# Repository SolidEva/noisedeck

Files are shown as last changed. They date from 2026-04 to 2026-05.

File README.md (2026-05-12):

# noisedeck

a cyberdeck for dealing in noise
runs [prawnix](http://github.com/SolidEva/prawnix)

## v2

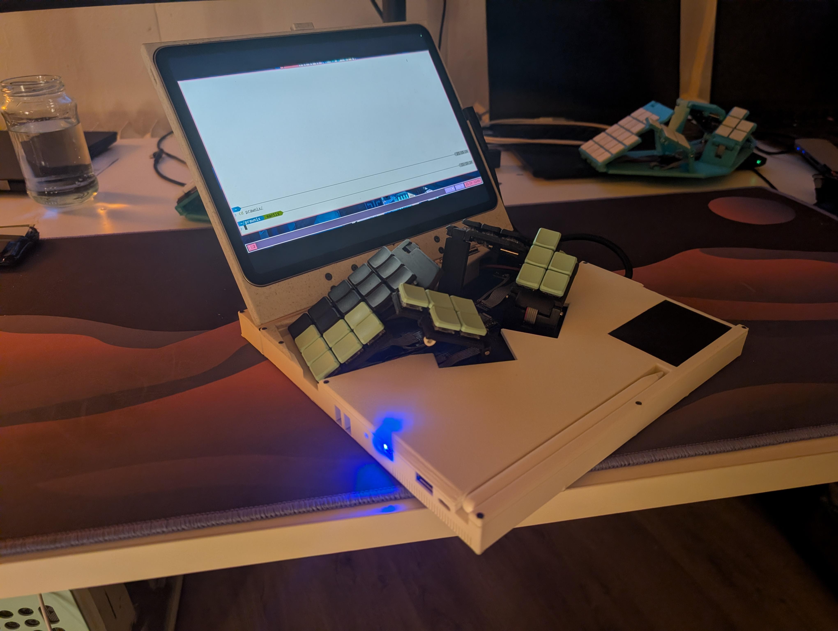
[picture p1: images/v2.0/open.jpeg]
front_open


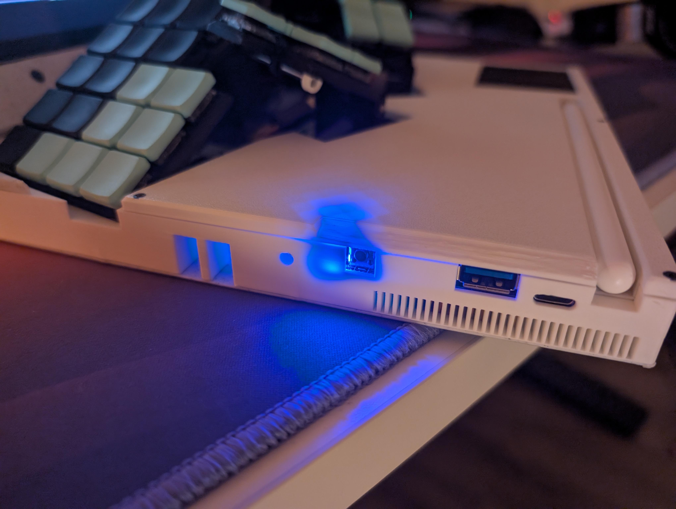
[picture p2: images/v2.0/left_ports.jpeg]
ports_left


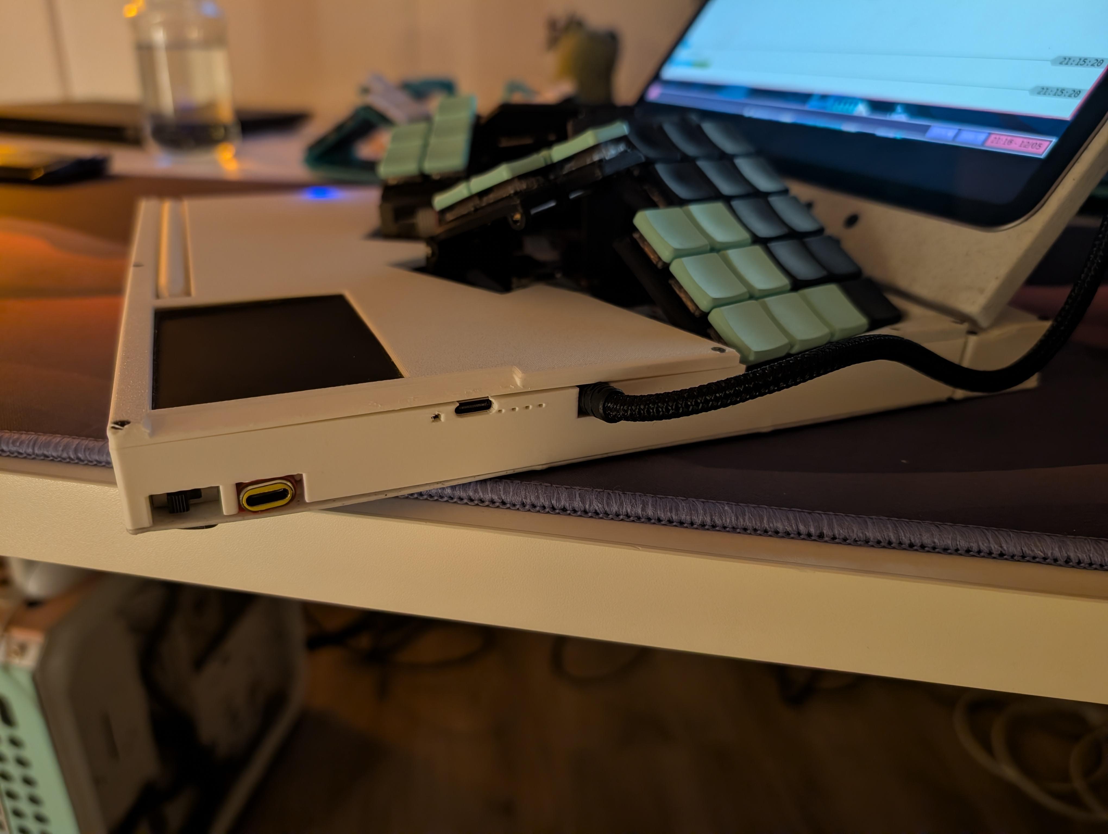
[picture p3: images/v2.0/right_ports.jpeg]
ports_right


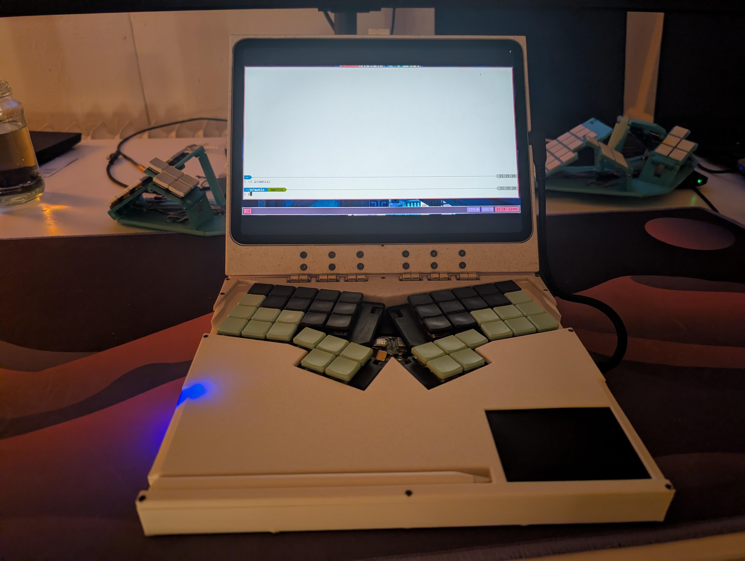
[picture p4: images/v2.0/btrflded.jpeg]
btrfld_folded


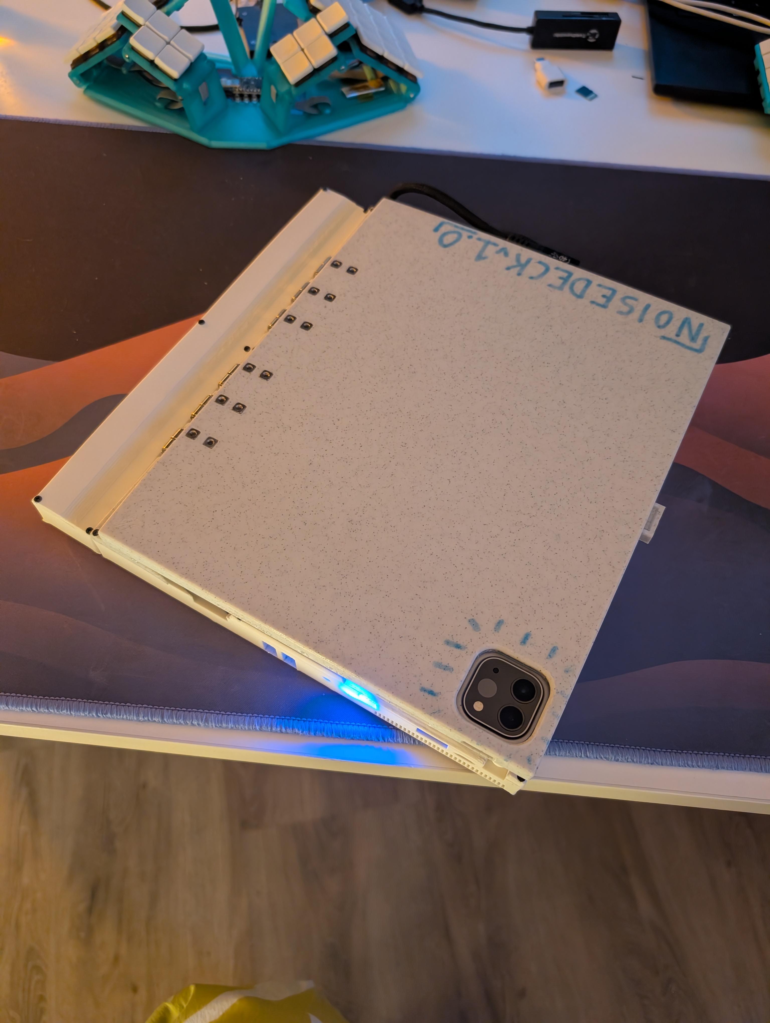
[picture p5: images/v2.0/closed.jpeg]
closed


### features
- rk3588s SBC (firefly roc-rk3588s-pc)
- btrfld keyboard
- trackpad
- ipad: magnetically mounted acting as screen via usbc hdmi capture card
- 1x usb c data port
- 2x usb c charge port (one for ipad, other for main battery, supports usbc power delivery!)
- 1x usb a 3.0 port
- ipad pencil and charging cradle

### parts
ipad :p

btrfld keyboard: https://github.com/SolidHal/btrfld

rk3588s SBC: https://en.t-firefly.com/product/industry/rocrk3588spc#spec

hinges:
https://www.amazon.com/gp/product/B0BFWNJMCY/

hinge fasteners:
M3x16
M3 threaded, DIN 562 flat square nuts: https://www.amazon.com/M3nS-Printers-Stainless-Conform-Quantity/dp/B0BD2N9KTV

power switches:
https://www.amazon.com/dp/B075RC6TFB

apple pencil charging cradle:
https://www.amazon.com/Paiholy-Compatible-Generation-Lightweight-Convenient/dp/B0BMB7362T

midcase fasteners (plastic to plastic):
m2x5 and m2x6 tapered flat head self taping screws

cheap ipad magnetic folio case, torn apart to make the ipad mount

usbc right angle extension: https://www.amazon.com/dp/B0B71BZ4YF

battery & charging:
- 3x 18650s
- 3s BMS: https://de.aliexpress.com/item/1005006064385669.html
- usbc PD IP2369 based  battery charger board: https://de.aliexpress.com/item/1005008766304319.html
- XT30 plugs

cooling:
- fan: https://www.digikey.de/en/products/detail/wakefield-thermal-solutions/DB0620505H1A-BT0/12610355
- heatsink: https://www.digikey.de/en/products/detail/advanced-thermal-solutions-inc/ATS-1108-C1-R0/4146489
- screws, m3x5mm for heatsink, m2 for fan

video:
- a flat HDMI cable like: https://www.amazon.de/dp/B01787KZVG
- usbc 1080p hdmi capture card with usbc power delivery (lets us charge the ipad while in use): https://www.amazon.de/dp/B0DQDC3H46
- 4in usbc extension, for ipad power delivery, like https://www.amazon.com/dp/B0CSJMCCXW

- 4 port usb hub pcb: https://www.adafruit.com/product/5997

- mnt reform trackpad: https://shop.mntre.com/products/mnt-reform-capacitive-trackpad-module

### Assembly Notes

- glue eyeglass nosepads to bottomcase for feet
- hinges need to be filed/ground shorter on the side that would otherwise stick out through the bottom case
- cleaning out the hinge holes in the ipad enclosure is annoying. Recommend using a 46 gauge drill bit
- tear down the ipad folio case to just the parts required to hold the magnets in place. lets call this the "case core"
  - attach a thin film to the side of the case core that magnetizes to the ipad
  - superglue the case core into the ipad enclosure so that the ipad is held into the ipad enclosure magnetically

- battery wiring
    - so the schematic is cells --> BMS <----> ip2368
                                       |
                                    controller

more notes in build_notes.md

# V1

a cyberdeck for dealing in noise, v1

front_open

back_art

ports

btrfld_folded

closed

## features
- btrfld keyboard
- trackpad
- headphone jack
- mic jack
- 1x usb c data port
- 1x usb c charge port
- 1x usb a port
- ipad: magnetically mounted
- ipad pencil and charging cradle
- rpi zero 2 w + 5000mah battery

future:
- extra keys in topcase for common hotkeys(?)
- choc key one octave keyboard in topcase(?)
- pitch joystick/wheel that snaps back to the center

the rpi zero 2 w is ran so its usb is in gadget mode, so it tells the ipad it is an ethernet device.
with this you can setup a local network and ssh directly from the ipad to the rpi without using wifi
this leaves the wifi chipset useful for other things

## parts
hinges:
https://www.amazon.com/gp/product/B0BFWNJMCY/

hinge fasteners:
M3x8 countersunk fasteners: https://www.amazon.com/HanTof-Countersunk-Machine-Wrenches-Threaded/dp/B0B9HWVV61
M3x10 countersunk fasteners
M3 threaded, DIN 562 flat square nuts: https://www.amazon.com/M3nS-Printers-Stainless-Conform-Quantity/dp/B0BD2N9KTV

power switches:
https://www.amazon.com/dp/B075RC6TFB

apple pencil charging cradle:
https://www.amazon.com/Paiholy-Compatible-Generation-Lightweight-Convenient/dp/B0BMB7362T

midcase fasteners (plastic to plastic):
m2x5 and m2x6 tapered flat head self taping screws

cheap ipad magnetic folio case

btrfld keyboard: https://github.com/SolidHal/btrfld

usbc to 3x usbc (2 data, one power): https://www.amazon.com/gp/product/B09PFR2J82

usbc to 4x usbA : https://www.amazon.com/dp/B09N36LZSQ

usbA dac: https://www.amazon.com/dp/B01DLY3IW8

usbc right angle extension: https://www.amazon.com/dp/B0B71BZ4YF

rpi zero 2 w

5000mah battery

pcb usb hub https://www.amazon.com/dp/B09FX4QN4J

used to get a power only usbc port for charging the rpi battery: https://www.amazon.com/dp/B07VBV1PY5

## Assembly notes

case:
- use 52 gauge drill bit to clean out midcase holes for the m2 screws
- use 46 gauge drill bit to clean out topcase holes for the m2 screws
- use chamfer bit on bottomcase holes screws sit flush
- glue eyeglass nosepads to bottomcase for feet
- hinges need to be filed/ground shorter on the side that would otherwise stick out through the bottom case
- cleaning out the hinge holes in the ipad enclosure is annoying. Recommend using a 46 gauge drill bit
- tear down the ipad folio case to just the parts required to hold the magnets in place. lets call this the "case core"
  - attach a thin film to the side of the case core that magnetizes to the ipad
  - superglue the case core into the ipad enclosure so that the ipad is held into the ipad enclosure magnetically

- the 5000mah battery pack fits nicely under the dac.

dac must have a power switch, otherwise the ipad will always use it by default and never allow usage of the speakers

wiring:

The wiring is a bit messy, but it works and all fits with plenty of space:

wiring

ipad -> extension -> usbc/usbc 3 way splitter -> one usbc charging port, one usbc data port, and the usbc to usbA splitter

usbA splitter:
- port 1:
  - data and ground to headphone port dac
  - power to two switches on the left side of the noisedeck. One switch to the dac, other to pencil charger. Only use one of these at a time.
- port 2:
  - data only to rpi zero 2w data port. Power to nowhere
- port 3:
  - to pcb usb hub:
    - port 3a:
      - to btrfld
    - port 3b:
      - to trackpad
- port 4:
  - glued into the left side of the noisedeck, externally accessible usbA port

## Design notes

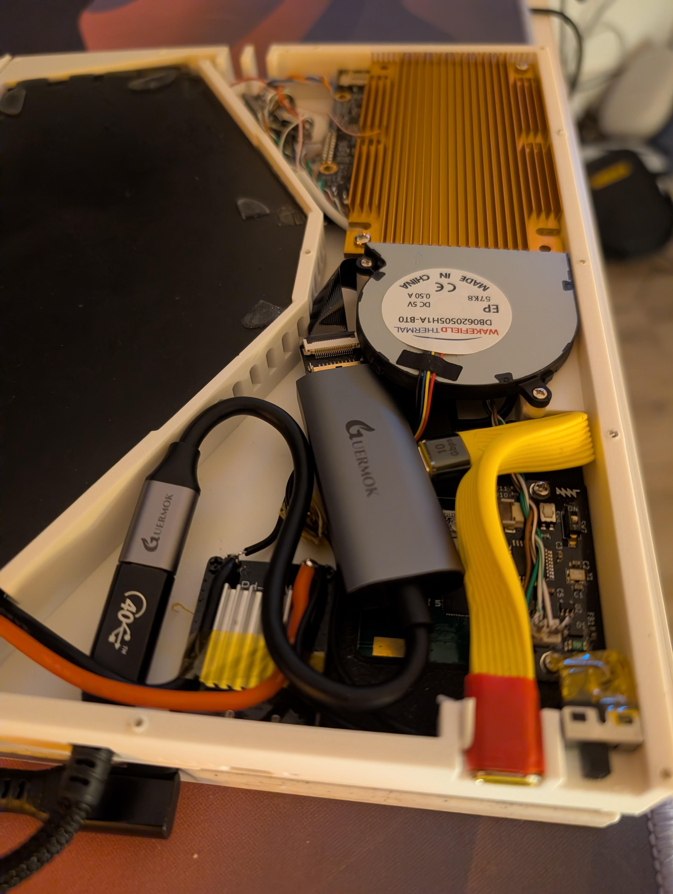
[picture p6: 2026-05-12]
images/v2.0/guts_closeup.jpeg

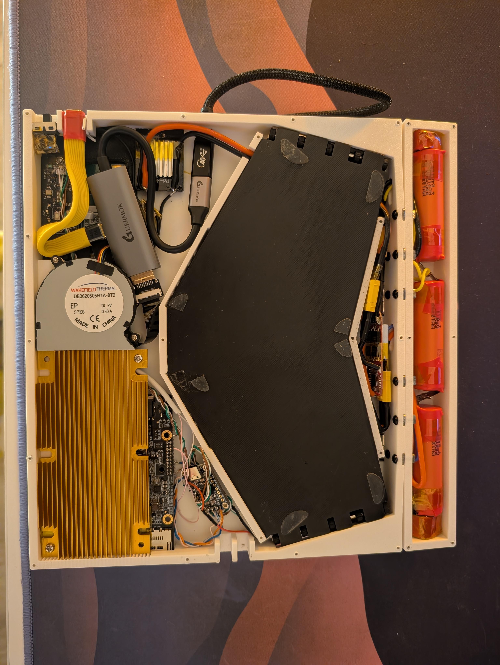
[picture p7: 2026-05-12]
images/v2.0/guts.jpeg

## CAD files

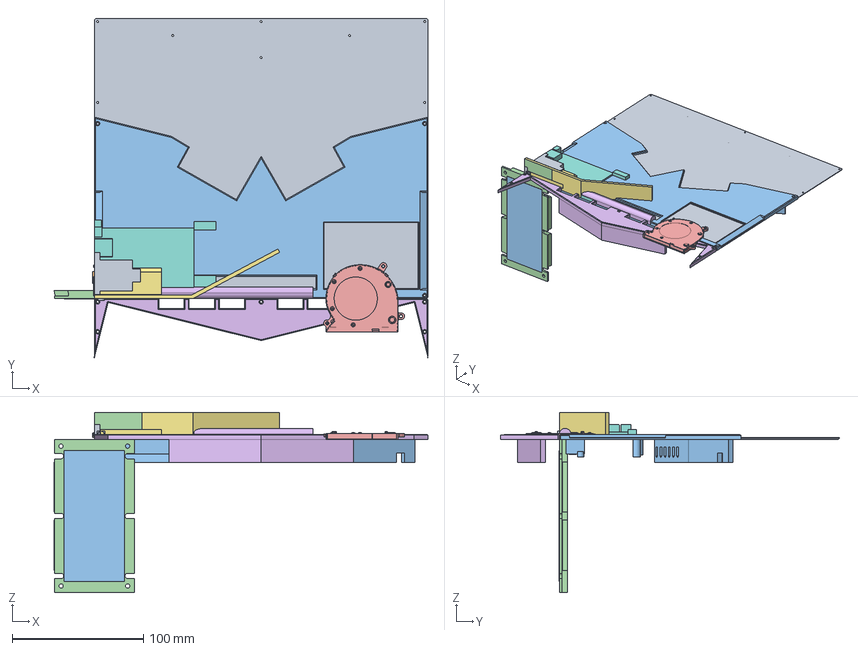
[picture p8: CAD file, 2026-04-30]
cad/case_assembly.FCStd
285.4 x 258.9 x 137.5 mm
bottomcase
usbc Charging port
ATS117061006-1108-C1-R0_FUSED
ATS117061006-1108-C1-R0_FUSED001
Dg12C04352tvdg
apple_pencil
audio_port_dac
controller
headphone_mic_jack
hinge_half
topcase_lower
topcase_lower_btrfld_support_center
topcase_lower_btrfld_support_outer
topcase_upper
topcase_upper_btrfld_support
trackpad_placeholder
usba_port
usba_port_smaller
usbc_cable_head
usbc_port
usbc_port_smaller

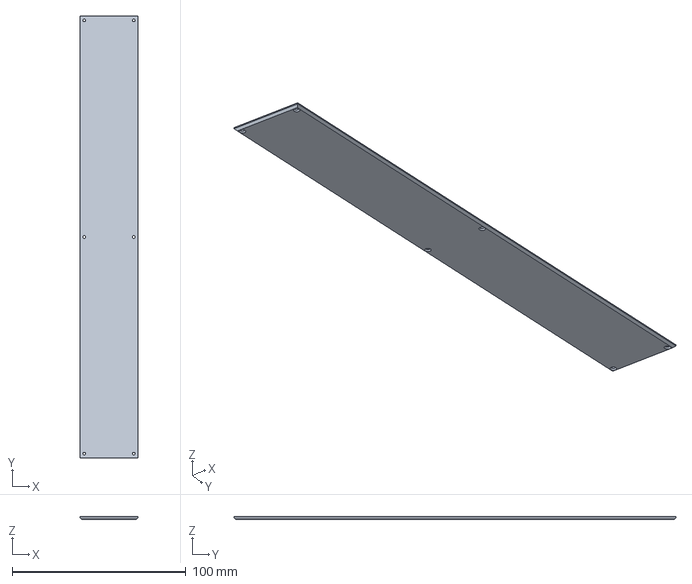
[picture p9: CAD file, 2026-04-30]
cad/stls/case_assembly-battery_bottomcase.3mf
33.5 x 254.6 x 1.50 mm

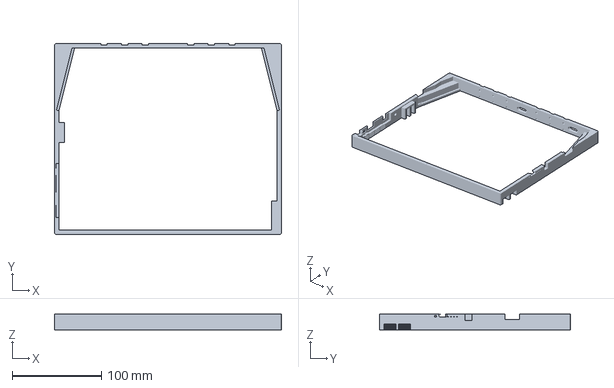
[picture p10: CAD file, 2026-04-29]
cad/stls/case_assembly-midcase.3mf
254.6 x 213.9 x 17.7 mm

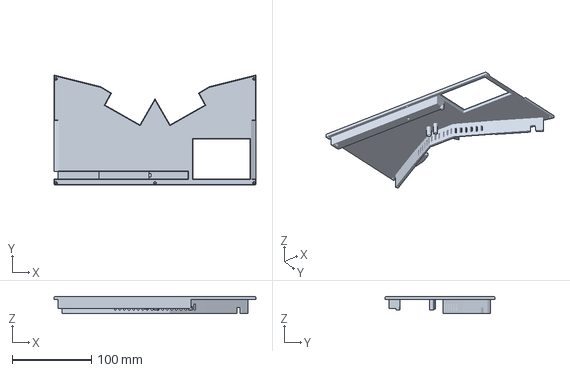
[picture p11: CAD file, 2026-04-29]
cad/stls/case_assembly-topcase_lower.3mf
254.6 x 138.6 x 21.7 mm

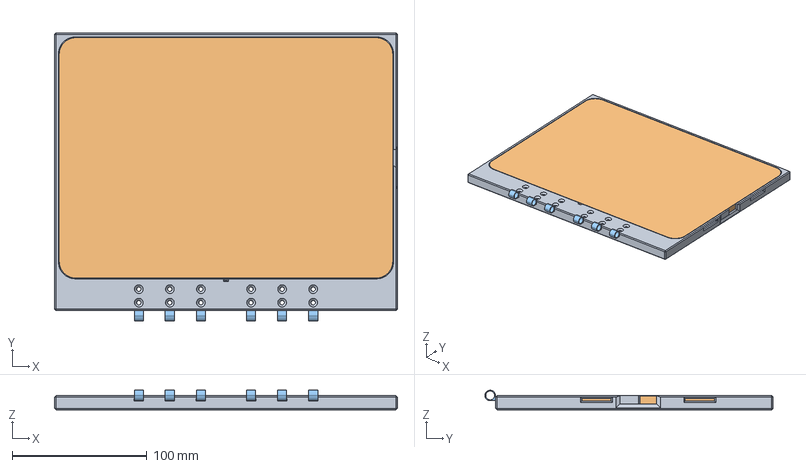
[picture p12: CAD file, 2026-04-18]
cad/lcd_assembly.FCStd
254.6 x 213.9 x 14.6 mm
ipad_enclosure
ipad11in4thgen
hinge_half x 6

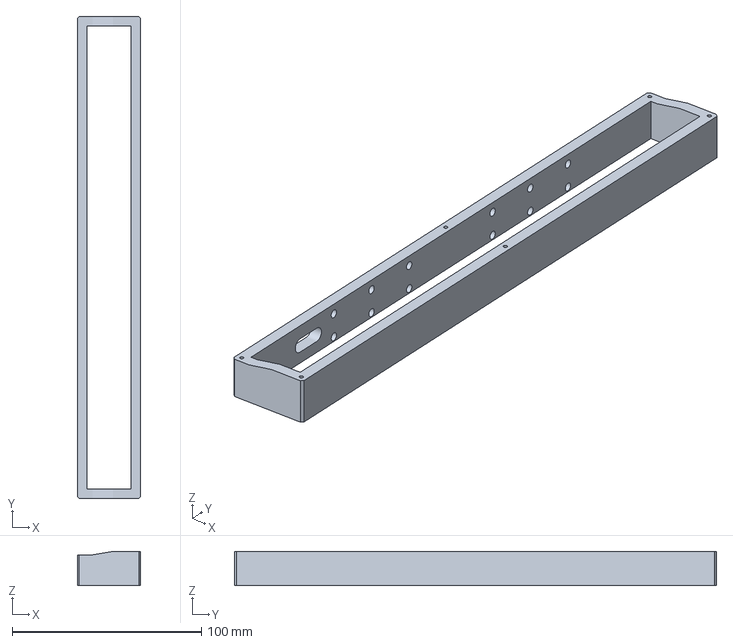
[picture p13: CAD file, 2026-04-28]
cad/stls/case_assembly-battery_midcase.3mf
33.5 x 254.6 x 18.0 mm

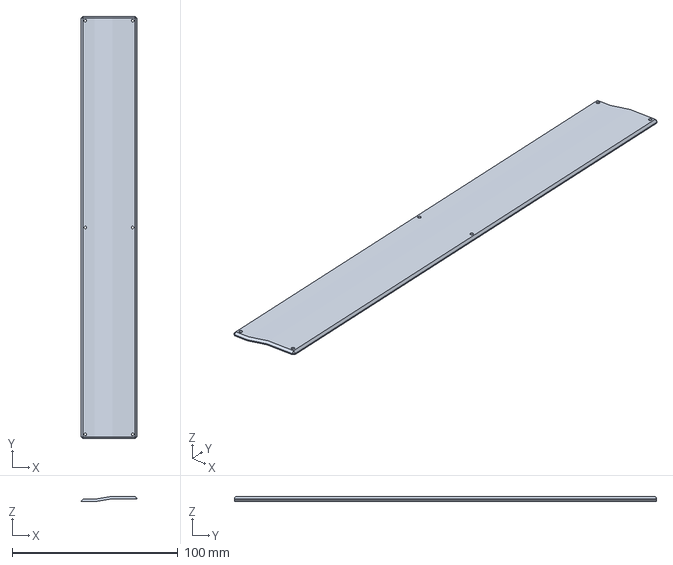
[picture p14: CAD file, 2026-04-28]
cad/stls/case_assembly-battery_topcase.3mf
33.5 x 254.6 x 3.30 mm

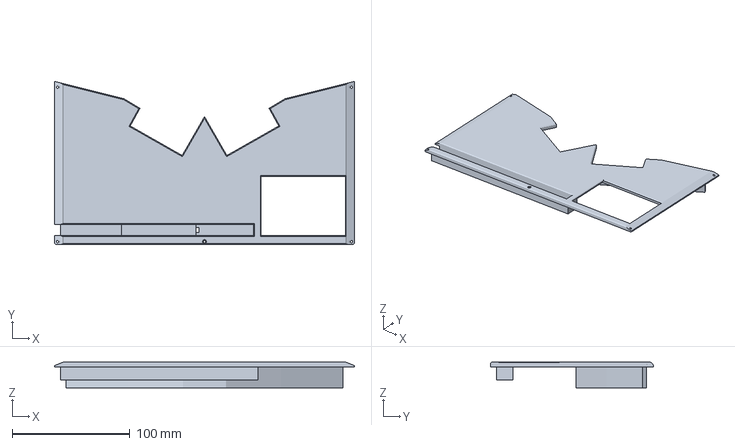
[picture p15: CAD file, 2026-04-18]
cad/stls/case_assembly-FullAssemblytopcase_lower001.3mf
254.6 x 138.6 x 21.7 mm

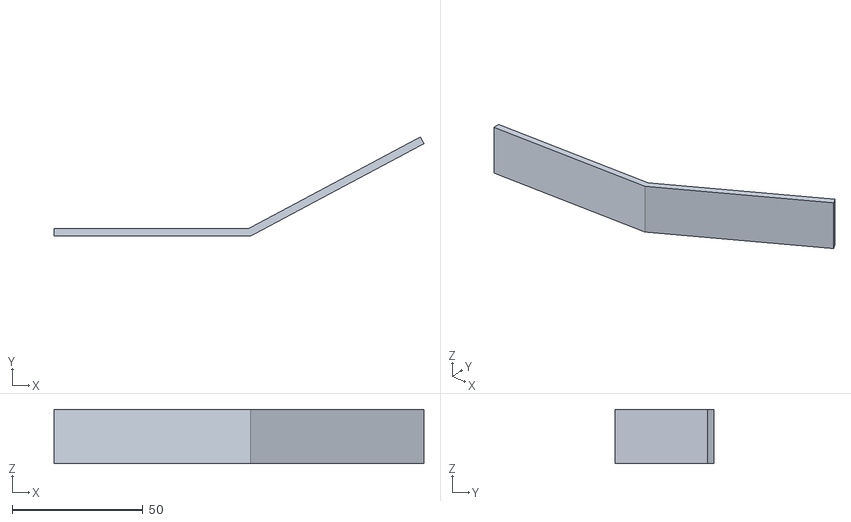
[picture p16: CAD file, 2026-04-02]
cad/stls/case_assembly-topcase_upper_btrfld_support.stl
141.4 x 37.9 x 20.7

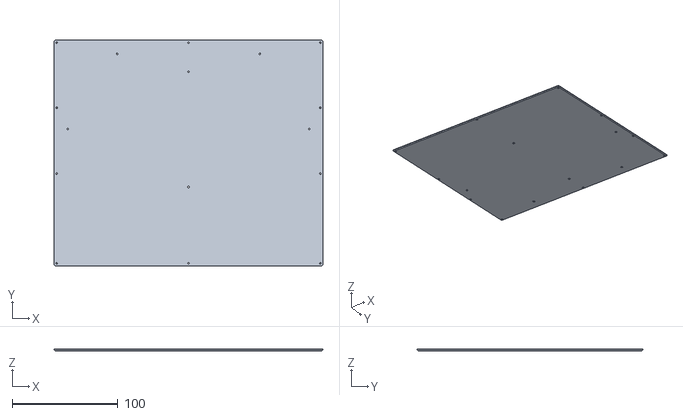
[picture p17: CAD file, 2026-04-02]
cad/stls/case_assembly-bottomcase.stl
254.6 x 213.9 x 1.50

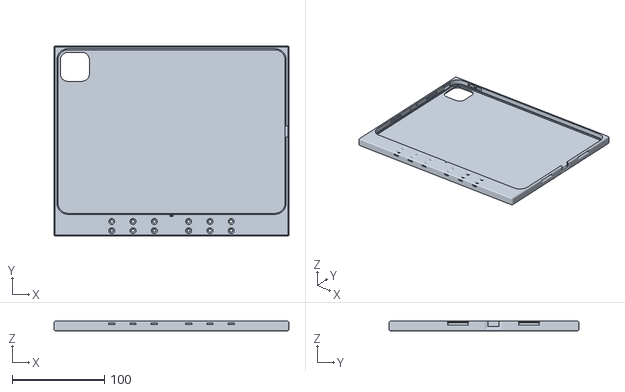
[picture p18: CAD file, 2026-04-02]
cad/stls/lcd_assembly-ipad_enclosure.stl
254.6 x 206.0 x 10.5

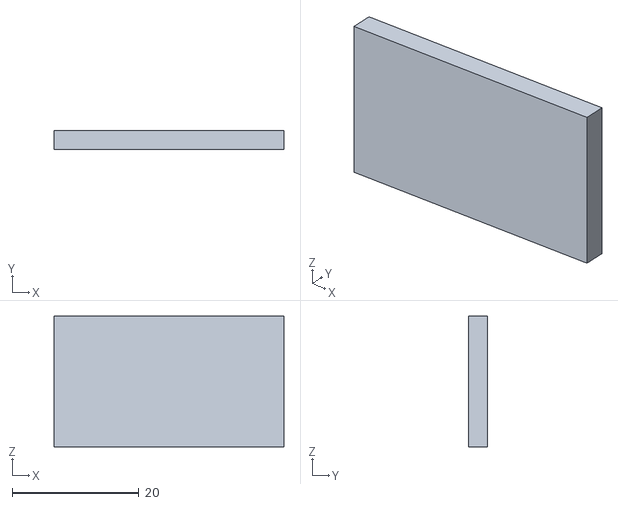
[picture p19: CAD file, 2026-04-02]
cad/stls/case_assembly-topcase_lower_btrfld_support_center.stl
36.3 x 3.00 x 20.7

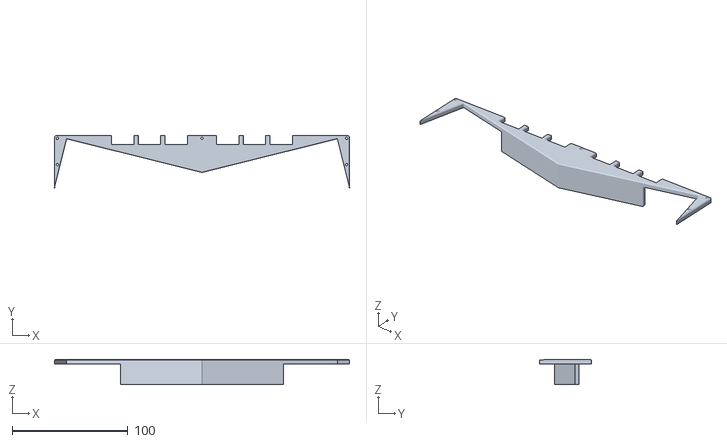
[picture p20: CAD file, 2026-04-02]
cad/stls/case_assembly-topcase_upper.stl
254.6 x 45.0 x 21.7

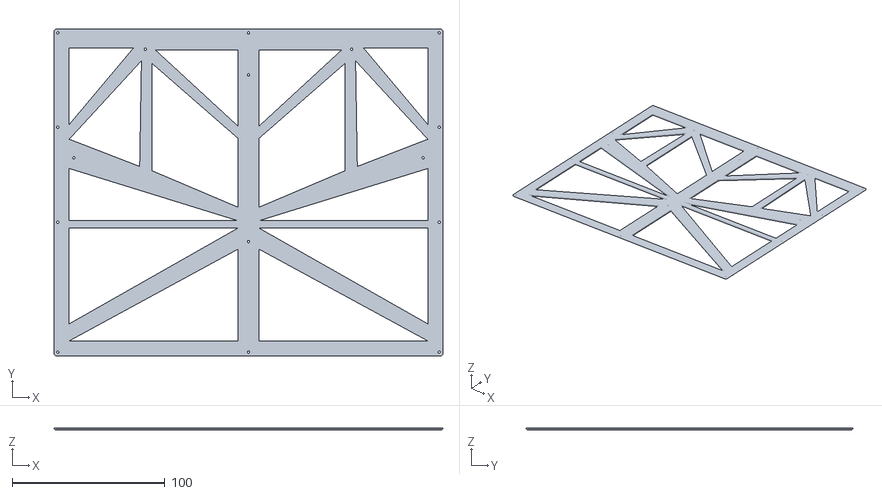
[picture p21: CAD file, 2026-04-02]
cad/stls/case_assembly-bottomcase-jig.stl
254.6 x 213.9 x 1.50

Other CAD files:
cad/stls/case_assembly-topcase_lower_btrfld_support_outer.stl
cad/noisedeck.FCStd
cad/btrfld.FCStd
cad/stls/case_assembly-midcase.stl
cad/stls/case_assembly-topcase_lower.stl

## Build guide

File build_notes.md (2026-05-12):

the 3d printed case is good, but the ipad on its own is a lousy computer. i want it around for logic pro and drawing, but otherwise i want it to be a linux machine.

options i have explored are:

1) remove the ipad, take a macbook screen & logic board and design a noisedeck around them.
    - this gets me a "real" computer, but is quite difficult to pull off
        - the hardest part is always
    - no more ipad, which means it can't be used for drawing/reading/tablet things

2) use the ipad as a remote desktop/vnc display for some SBC
    - battery management is annoying, would have to manage the SBC and ipad battery levels
    - rootfs encryption gets funny when a vnc server is required to get display
        - could work around this with ssh decryption, or even stick a light vnc server in the initramfs?
        - or just do it by feel & have ssh available for debug?
    - user login also gets funny, but i could also either do this by feel/ssh for debug or just auto start sway
    - create a headless display in the sway config with the ipad res, run `swaymsg create_output`
    - run wayvnc like `wayvnc 0.0.0.0 --render-cursor --disable-input --max-fps=60 --output=HEADLESS-1`
    - use manual local ethernet connection between the two

3) use the ipad as a display via an HDMI capture card!
    - use something like orion (by lux) (other options available)
    - this limits the ipad to be just a display, uses standard display tech! no special software on the SBC required
    - need to be aware of input lag (hopefully minimal?)

## Battery

- need some way to get 12v for the board
    - actually supports 9V~24V wide voltage input!
- not a lot of room in the palmrest for a battery
- could fit 1x 18650?
    - need something like https://www.aliexpress.us/item/3256810401027521.html
    - https://www.amazon.de/-/en/Kuulaa-Powerbank-External-Battery-Compact/dp/B0GC6J7VTJ does 12v allegedly
- could have an expanded battery pack on the back behind the hinge?
    - 3x 18650s?
- adafruit has https://www.adafruit.com/product/5450 which is a usbc pd to 12v dc barel jack

PLAN:
- 3x 18650s - ordered
- need a 3s BMS
- need a way to get 12v to the BMS
- want to be able to plug any usbc charger in, and be able to charge quickly
- so we need a bidirectional buck/boost usbc that outputs 12v
    - full keywords: bidirectional usbc 3s
    - IP2368 https://old.reddit.com/r/18650masterrace/comments/1euw3zc/ip2368_breakout_board_external_power_output_not/
    - IP5389

- so the schematic is cells --> BMS <----> ip2368
                                       |
                                    controller

- can we fit an IP2368 board in the palmrest?
    - yea, i think so?

- could use something like this
    - https://www.aliexpress.us/item/3256805900941544.html?gatewayAdapt=glo2usa4itemAdapt#nav-specification
    - but it only does boost, no buck
    - aparently this doesnt work correctly

- battery case
    - chamfers
    - case screw holes
    - bottom case
    - where to run battery wires?
        - could maybe run them through the midcase wall/bottom in a trench depending on the width?
        - could run them over the btrfld with a connector so the btrfld is removable?
            - near the btrfld hinge perhaps?
                - need to stick a connector either in the battery pack, or in the noisedeck palmrest so we can remove the btrfld
                    - ~35mm in
                    - 4.75 from bottom
                    - 10.2 wide 5.8 tall
            - the wires are ~3mm diameter
            - the connectors are 5.2x10.2 mm

    - longer hinge screws to connect battery pack to laptop

## Cooling
- long, thin cooler that spans most of the width of the case?
    - fan
        - tip for fan control https://github.com/Joshua-Riek/ubuntu-rockchip/discussions/558
        - these 2 are nearly identical
            - https://www.digikey.com/en/products/detail/sunon-fans/4548HQ-EG50040S1-CG61-S9A/12685816
            - https://www.digikey.de/en/products/detail/wakefield-thermal-solutions/DB0620505H1A-BT0/12610355
                - but this one is in stock
                - WENT WITH THIS
    - heatsink options
        - if it doesn't go over the pencil charging area: max size is 6.87 tall, 53mm wide, ~160mm long (variable)
            - https://www.digikey.de/en/products/detail/fischer-elektronik/SK-511-100-SA/25830853 6mm tall, 100mm long, 45 mm wide
        - if it does (we could thin out the bottom of the pencil charger): 6.87 tall, 67mm tall, ~160mm long
            - WENT WITH THIS
            - https://www.digikey.de/en/products/detail/advanced-thermal-solutions-inc/ATS-1108-C1-R0/4146489

    - screws, m3x5mm for cooler, m2 for fan

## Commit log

2026-04-02 check in stls, update cad to freecad 1.1
    [case_assembly-bottomcase-jig.stl, case_assembly-bottomcase.stl, case_assembly-midcase.stl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]
2026-04-02 place controller, add battery notes
    [btrfld.FCStd, case_assembly.FCStd, lcd_assembly.FCStd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]
2026-04-10 clean up controller port fitment
    [case_assembly-midcase.3mf, case_assembly.FCStd, noisedeck.FCStd]
2026-04-11 import cooler
    [case_assembly-midcase.3mf, case_assembly.FCStd]
2026-04-11 thin out bottom of pencil dock to fit larger cooler
    [case_assembly.FCStd, noisedeck.FCStd]
2026-04-11 add fan, begin work on battery extension
    [case_assembly.FCStd, noisedeck.FCStd]
2026-04-17 initial batterypack work
    [case_assembly.FCStd, noisedeck.FCStd]
2026-04-18 added midcase and battery pack wire hold
    [case_assembly.FCStd]
2026-04-18 add topcase battery wire hole, bevel palmrest angles
    [case_assembly-FullAssemblytopcase_lower001.3mf, case_assembly-topcase_lower.3mf, case_assembly.FCStd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]
2026-04-18 add air intake slots
    [case_assembly-topcase_lower.3mf, case_assembly.FCStd, noisedeck.FCStd]
2026-04-18 add exhaust holes, cooling mount points
    [btrfld.FCStd, case_assembly-midcase.3mf, case_assembly.FCStd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]
2026-04-20 widen battery pack
    walls must be 5mm wide to allow for the bottom case screw holes
    which have to have enough space for the chamfer
    could remove the bottom case chamfer and save ~4mm
    [case_assembly-battery_midcase.3mf, case_assembly.FCStd]
2026-04-28 functional batter midcase and topcase
    [case_assembly-battery_midcase.3mf, case_assembly-battery_topcase.3mf, case_assembly.FCStd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]
2026-04-29 add middle midcase battery hole
    [case_assembly-topcase_lower.3mf, case_assembly.FCStd, noisedeck.FCStd]
2026-04-29 add charger port
    [case_assembly-midcase.3mf, case_assembly.FCStd, noisedeck.FCStd]
2026-04-30 add battery bottomcase
    [case_assembly.FCStd, noisedeck.FCStd]
2026-04-30 add channel for pencil charging cable
    otherwise it conflicts with the cooler
    [case_assembly-battery_bottomcase.3mf, case_assembly.FCStd, noisedeck.FCStd]
